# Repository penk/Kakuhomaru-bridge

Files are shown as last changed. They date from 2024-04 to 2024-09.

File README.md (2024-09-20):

# The Kakuhomaru Bridge Pickup for Electric Violins 

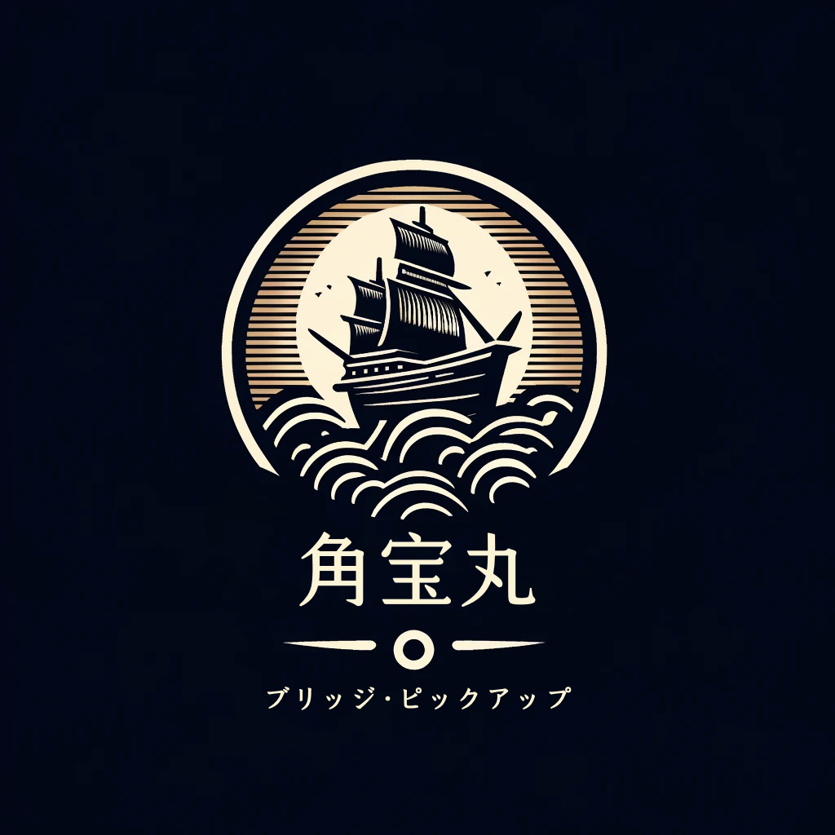
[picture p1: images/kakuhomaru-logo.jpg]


The Kakuhomaru (角宝丸) bridge is a piezoelectric pickup for electric violins, designed with a ‘one-sensor-per-string’ approach to capture each note with clarity and richness.

🔊 Listen to the open string sample here:

https://github.com/penk/Kakuhomaru-bridge/assets/61878/6f59927d-60b6-4801-80bd-5c879a68bae8

## Bill of materials  

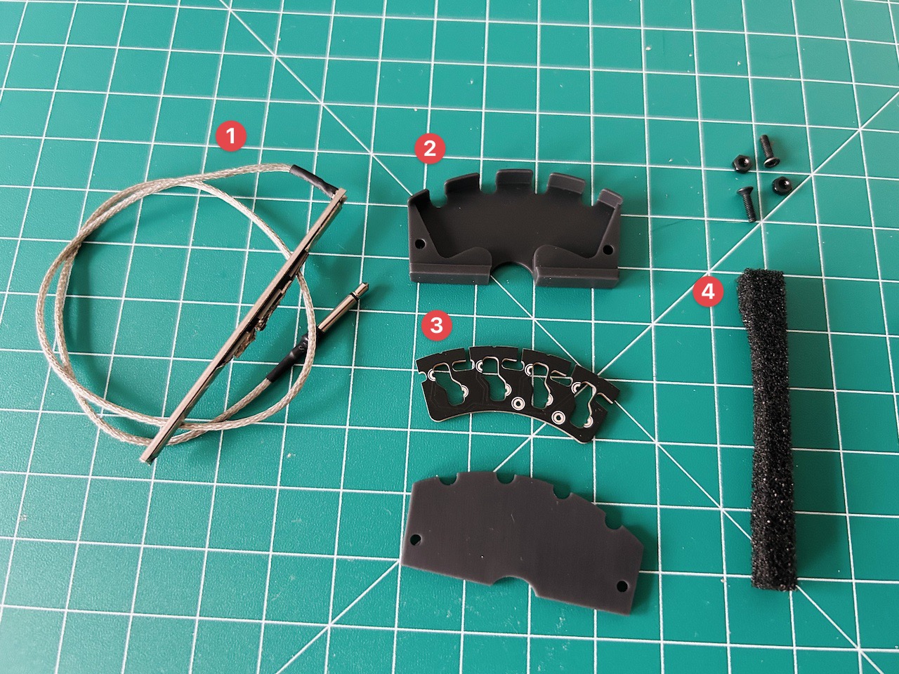
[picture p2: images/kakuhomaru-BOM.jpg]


Each Kakuhomaru bridge is composed of 4 main parts:

1. Piezoelectric rods and shielded cable (repurposed from guitar undersaddle pickups).
2. 3D printable case (available in both [low profile](./case/kakuhomaru-case-lowp.stl) and [high profile](./case/kakuhomaru-case-highp.stl)).
3. Custom printed circuit board (PCB) with castellated holes.
4. Semi-rigid electronically conductive foam (I'm using [this one](https://www.distrelec.de/en/conductive-foam-305x305x6mm-rnd-rnd-600-00067/p/30130228) which has a `30 ohm-meter (Ω·m)` volume resistance).

While some parts may require a few days of lead time, the assembly is straightforward and DIY-friendly once all components are in hand.

## Ordering the PCB

To get started with your PCB order, upload the [production file](./production/kakuhomaru-bridge-gerbers.zip) to your preferred PCB manufacturer, such as JLCPCB or PCBWay. Ensure you select `Castellated Holes`—essential for the functionality of our bridge pickup.

Here are the specifications I used for our prototype:

```
PCB Thickness: 1.6 mm 
PCB Color: Black
Remove Order Number: Yes
Castellated Holes: Yes
Edges: 2
```

For reference, ordering 10pcs from JLCPCB cost approximately $40. This should help you budget for your build.

## Assembly Instructions 

- Step 1: Attach the Piezoelectric Rods

    Carefully slice open the heat shrink tubing of the under-saddle pickup with a utility knife to retrieve the piezoelectric ceramics. Position the ceramics with the positive end towards the  E string (treble side) and the marked negative end towards the G string (bass side) . Fix them in place on the PCB using a tiny drop of CA glue at each end.

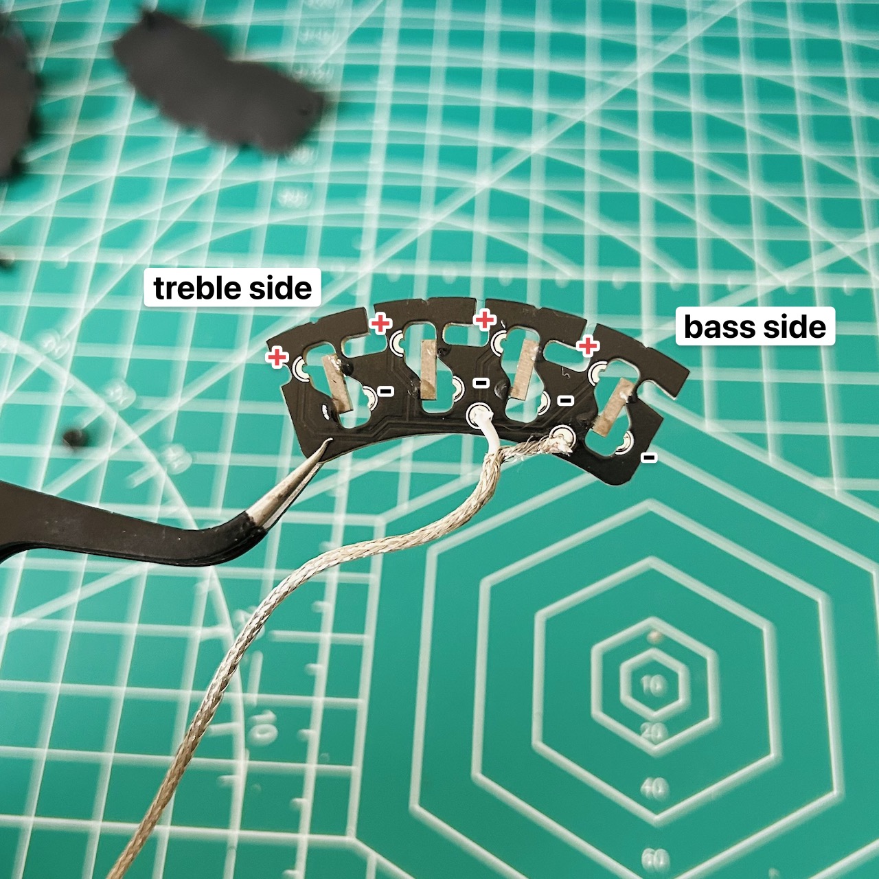
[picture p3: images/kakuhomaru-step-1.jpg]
    

- Step 2: Solder the Shielded Cable & Insert the Conductive Foam

    Strip back a small portion of the shielded cable to expose the central positive wire. Solder this wire to the positive through-hole on the PCB. Attach the braided mesh, which acts as the negative wire, to the `GND` (ground) through-hole. Then, insert conductive foam into the eight castellated holes, using approximately 5mm cubic pieces.

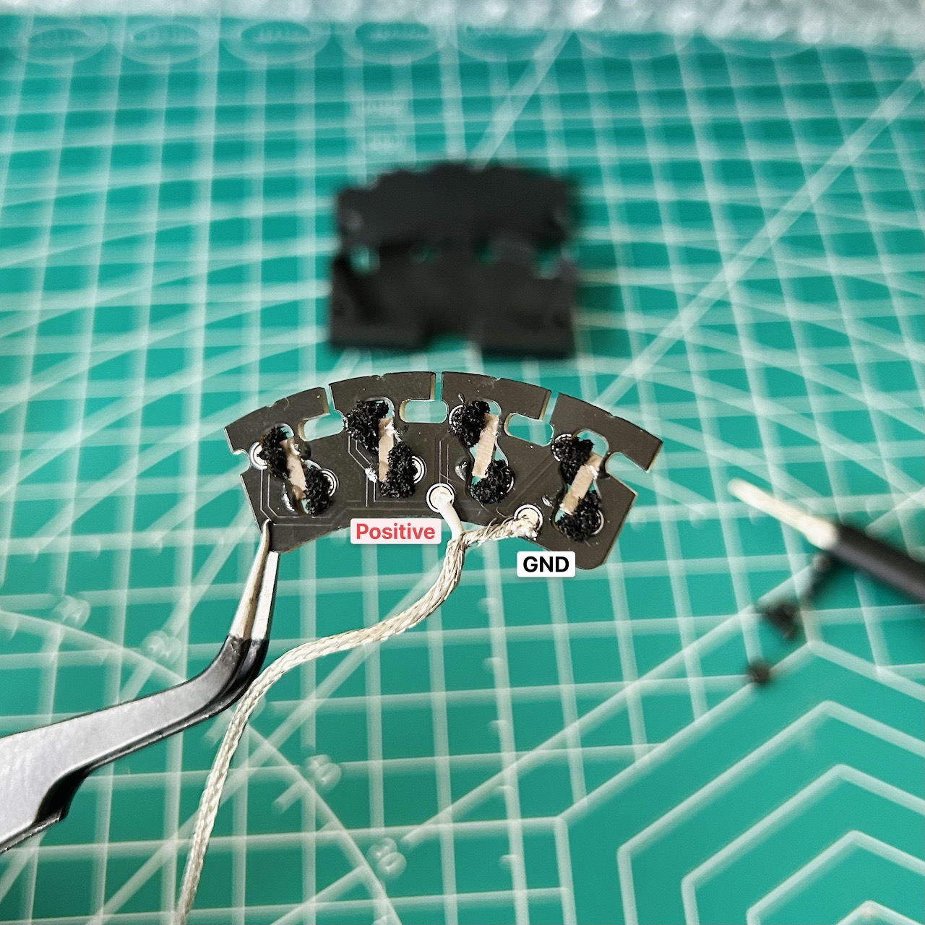
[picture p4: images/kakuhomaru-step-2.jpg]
    

- Step 3: Close the Protective Case  

    Place the PCB assmebly inside the [3D printed case](./case/) and secure it with two M2x10 screws. 

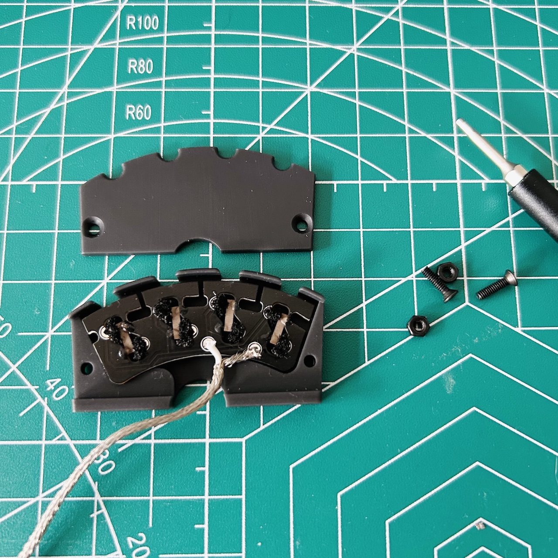
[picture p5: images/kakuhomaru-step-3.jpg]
    

🔊 Test the bridge assembly with an amplifier once you complete the assembly to ensure proper functionality.

https://github.com/penk/Kakuhomaru-bridge/assets/61878/055f79b9-ad49-477b-b956-cf757c91dd27

## Setting up 

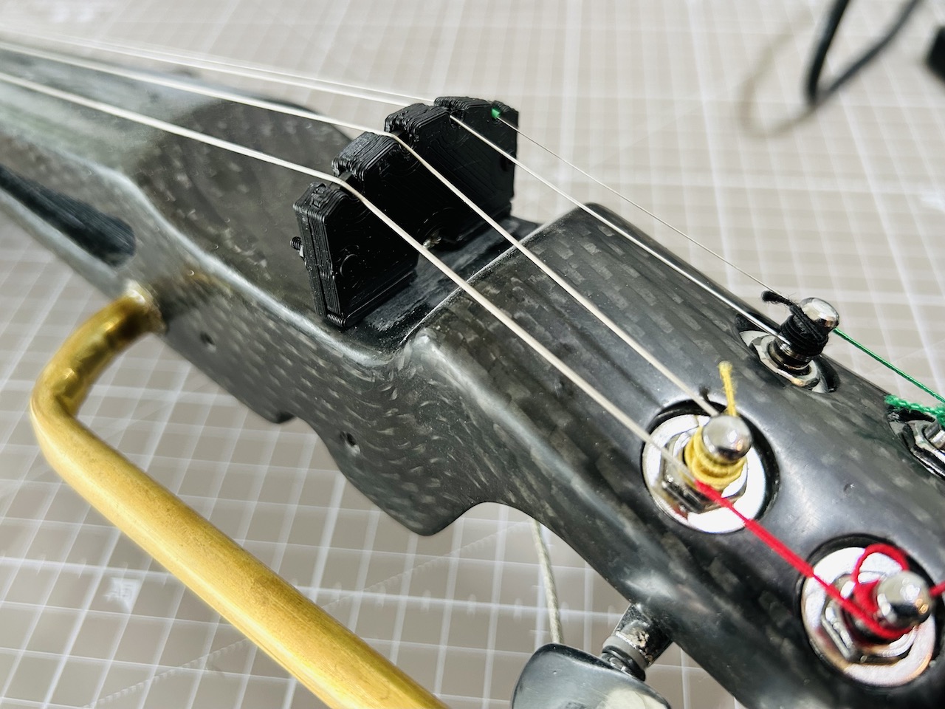
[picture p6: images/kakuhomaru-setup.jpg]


- Shielding: There's no need for copper shielding tape due to the PCB's integrated ground plane, which reduces interference.
- Grounding: Establish a grounding connection by connecting the shielded cable to the tuning pegs (if applicable) or directly to the string ends, depending on your violin setup.
- Bridge Shaping: Sand the bridge feet as you normally would and use a pencil to mark the grooves on the edge of the PCB for smooth string sliding.

## Further Customization

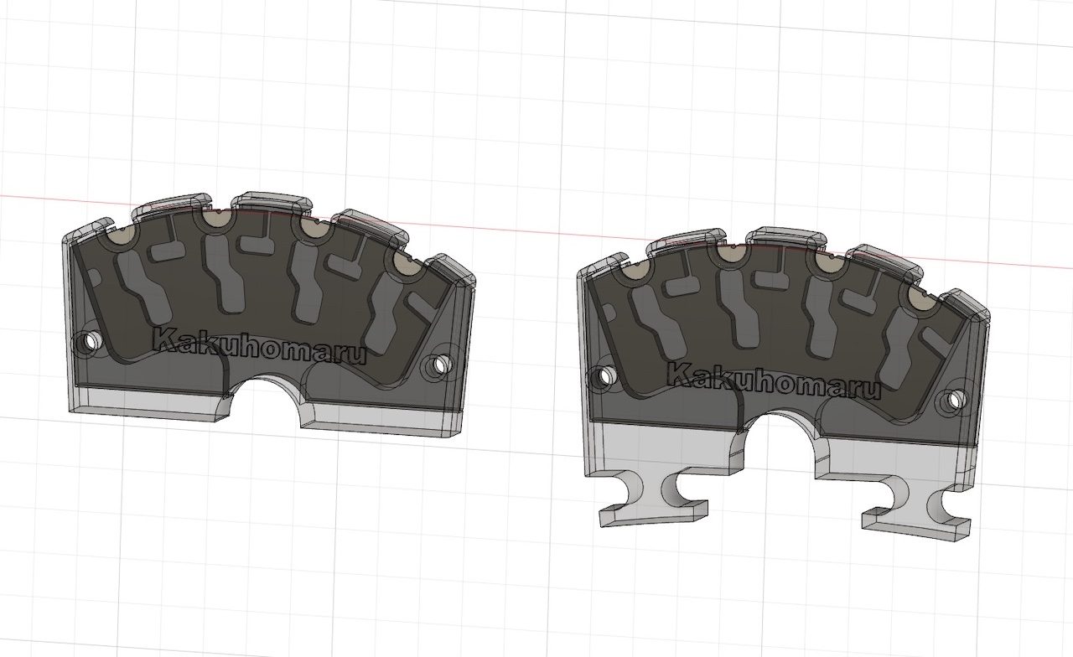
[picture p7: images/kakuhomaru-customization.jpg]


For those looking to tailor the bridge pickup to different sizes or heights, an [editable STEP file](./case/kakuhomaru-case.step) is available. This file allows you to make precise adjustments to the bridge to perfectly fit your instrument's unique specifications.

Additionally, if your setup requires a pickup for five or more strings, you can take advantage of the [fully editable KiCad project](./kicad). This project includes a [DXF outline](./case/kakuhomaru-PCB-outline.dxf), enabling you to design and customize your PCB to accommodate the specific needs of multi-string electric violins.

## Copyright and License
Copyright (c) 2024 Penk Chen. All rights reserved.

All files are licensed under MIT license, see the [LICENSE](LICENSE) for more information.

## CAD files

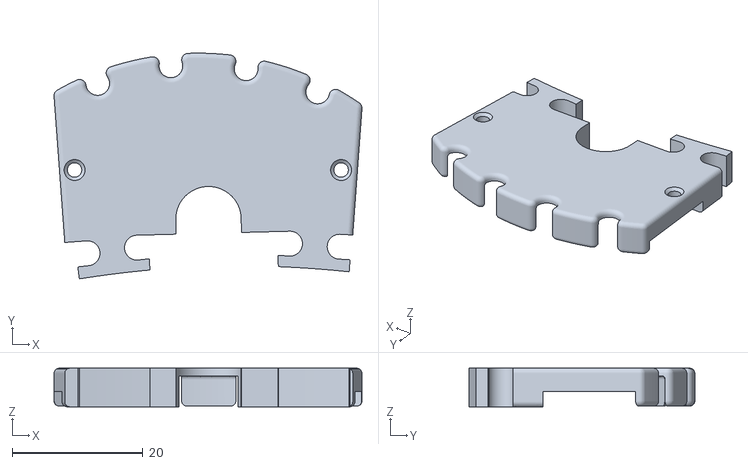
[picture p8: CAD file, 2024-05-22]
case/kakuhomaru-case-highp.stl
47.1 x 34.5 x 5.90

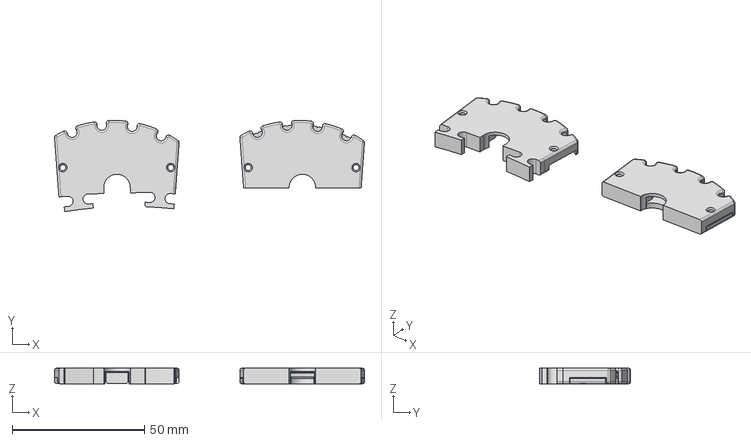
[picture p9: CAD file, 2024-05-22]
case/kakuhomaru-case.step
117.1 x 34.5 x 5.90 mm

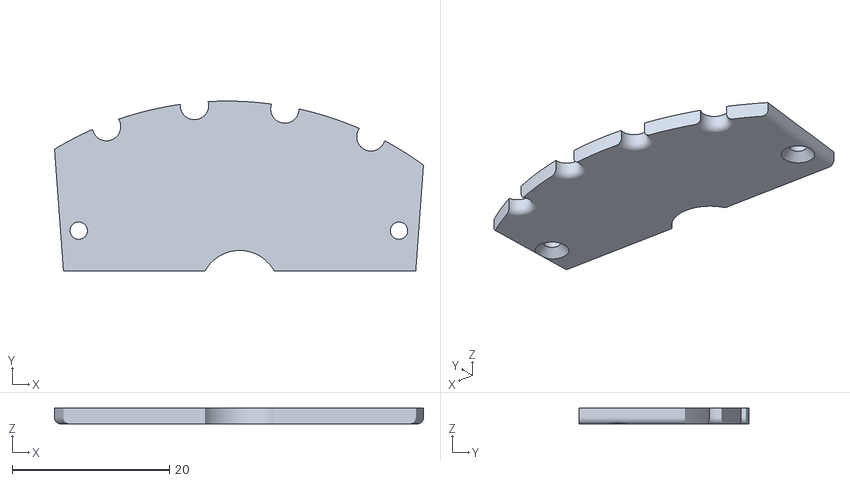
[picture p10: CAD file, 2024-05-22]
case/kakuhomaru-case-cover.stl
46.9 x 21.6 x 2.00

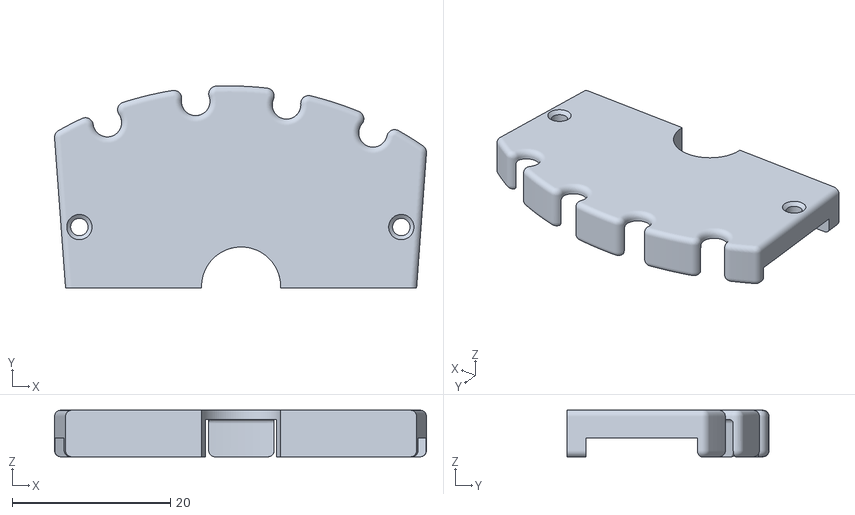
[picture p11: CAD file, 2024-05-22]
case/kakuhomaru-case-lowp.stl
47.1 x 25.6 x 5.90

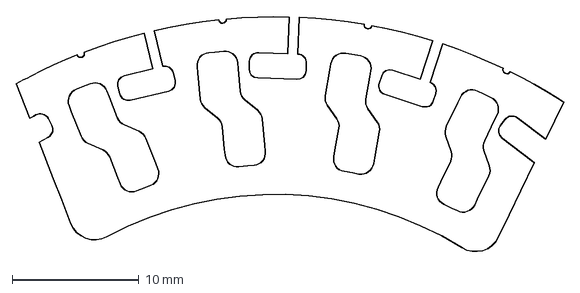
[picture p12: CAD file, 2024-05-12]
case/kakuhomaru-PCB-outline.dxf
43.2 x 18.6 mm

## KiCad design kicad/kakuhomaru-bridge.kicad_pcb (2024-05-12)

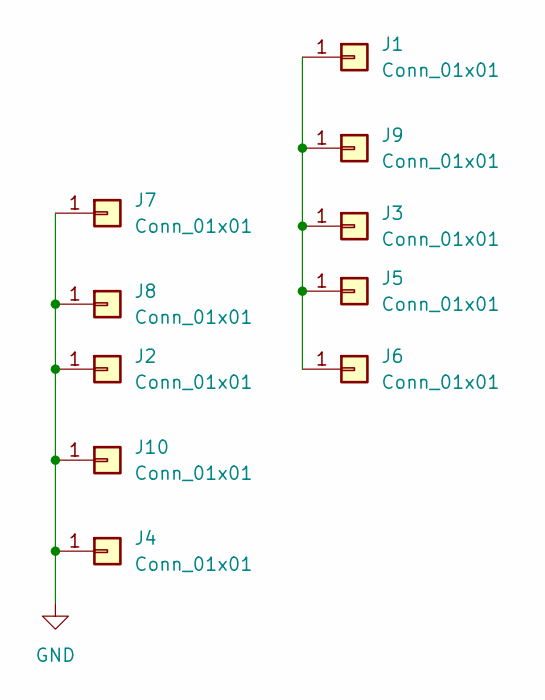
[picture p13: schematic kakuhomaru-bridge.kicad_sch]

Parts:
J1, J2, J3, J4, J5, J6, J7, J8, J9, J10: Conn_01x01; Pin_D1.0mm_L10.0mm

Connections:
GND: J2.1, J4.1, J7.1, J8.1, J10.1
unnamed: J1.1, J3.1, J5.1, J6.1, J9.1

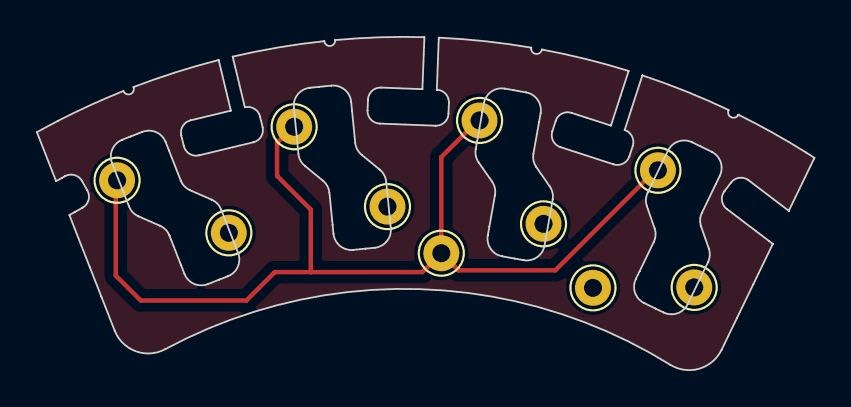
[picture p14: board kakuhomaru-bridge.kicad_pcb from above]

Board: 2 copper layers, 43.2 x 18.5 mm, 10 parts (0 on the bottom side), 2 nets.

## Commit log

2024-04-22 Update README and add files
    [kakuhomaru-PCB-outline.dxf, kakuhomaru-bridge.kicad_pcb, kakuhomaru-bridge.kicad_sch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]
2024-05-12 Update PCB & case design
    [kakuhomaru-PCB-outline.dxf, kakuhomaru-bridge.kicad_pcb, kakuhomaru-case-cover.stl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]
2024-05-22 Update case design
    [kakuhomaru-case-cover.stl, kakuhomaru-case-highp.stl, kakuhomaru-case-lowp.stl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]
2024-05-22 Update BOM reference picture
